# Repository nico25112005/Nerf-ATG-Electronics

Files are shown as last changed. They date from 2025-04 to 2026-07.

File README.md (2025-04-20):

# Nerf-ATG-Electronics

This repository contains the electronic design files for a custom printed circuit board (PCB) developed to enhance Nerf LaserOps blasters. The board utilizes an ESP32-S3 microcontroller to manage the blaster's functions and communicate via Bluetooth with a Unity application.

## Features

- Custom PCB design for Nerf LaserOps blasters
- ESP32-S3 microcontroller for improved performance and connectivity
- Bluetooth Classic for communication with a Unity application

## Installation

1. **PCB Assembly:**

   - Solder the components onto the board as per the schematic and Bill of Materials (BOM).

2. **Firmware Flashing:**

   - Flash the firmware onto the ESP32-S3. The firmware can be found in the Nerf-ATG-Firmware repository.

3. **Integration:**

   - Replace the original mainboard in the Nerf LaserOps blaster with the custom PCB.

4. **Unity App Setup:**

   - Install the Unity app from the Nerf-ATG-App repository on your device.
   - Pair the blaster with the app via Bluetooth.

## Usage

1. **Power On:**

   - Turn on the blaster.

2. **Connect to App:**

   - Open the Unity app and connect to the blaster via Bluetooth.

3. **Operation:**

   - Use the app to control and monitor the blaster’s functions.

## Contributing

Contributions are welcome! We are currently seeking assistance with programming the ESP32. If you have experience with ESP32 development, please consider contributing to the Nerf-ATG-Firmware repository. Please fork the repository and submit a pull request with your changes.

## Contact

For questions or support, please contact nico25112005.

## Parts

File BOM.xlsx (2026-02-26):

Reference | Qty | Value | DNP | Exclude from BOM | Exclude from Board | Footprint | Datasheet
BT2 | 1 | Battery (7.2V-10.8V) |  |  |  |  | ~
C2,C3,C4 | 3 | 100nF |  |  |  | PCM_JLCPCB:C_0603 | https://www.lcsc.com/datasheet/lcsc_datasheet_2211101700_YAGEO-CC0603KRX7R9BB104_C14663.pdf
C6 | 1 | 47pF |  |  |  | PCM_JLCPCB:C_0603 | https://www.lcsc.com/datasheet/lcsc_datasheet_2304140030_Samsung-Electro-Mechanics-CL10C470JB8NNNC_C1671.pdf
C7,C12,C14,C15,C16 | 5 | 22uF |  |  |  | PCM_JLCPCB:C_0805 | https://www.lcsc.com/datasheet/lcsc_datasheet_2304140030_Samsung-Electro-Mechanics-CL21A226MAQNNNE_C45783.pdf
C8,C9 | 2 | 1uF |  |  |  | PCM_JLCPCB:C_0603 | https://www.lcsc.com/datasheet/lcsc_datasheet_2304140030_Samsung-Electro-Mechanics-CL10A105KB8NNNC_C15849.pdf
C10,C11,C13 | 3 | 10uF |  |  |  | PCM_JLCPCB:C_0805 | https://www.lcsc.com/datasheet/lcsc_datasheet_2304140030_Samsung-Electro-Mechanics-CL21A106KAYNNNE_C15850.pdf
Camera_Interface1 | 1 | Conn_02x08_Counter_Clockwise |  |  |  |  | ~
J1 | 1 | Conn_01x02 |  |  |  | Connector_PinHeader_2.54mm:PinHeader_1x02_P2.54mm_Horizontal | ~
J2 | 1 | Conn_01x02_Socket |  |  |  | Connector_PinSocket_2.54mm:PinSocket_1x02_P2.54mm_Horizontal | ~
J3 | 1 | Dome |  |  |  | Connector_JST:JST_EH_B6B-EH-A_1x06_P2.50mm_Vertical | ~
J4 | 1 | USB_C_Receptacle_USB2.0_14P |  |  |  |  | https://www.usb.org/sites/default/files/documents/usb_type-c.zip
J5 | 1 | Motor1 |  |  |  | Connector_JST:JST_EH_B2B-EH-A_1x02_P2.50mm_Vertical | ~
J6 | 1 | Motor2 |  |  |  | Connector_JST:JST_EH_B2B-EH-A_1x02_P2.50mm_Vertical | ~
J7 | 1 | Speaker |  |  |  |  | ~
J8 | 1 | Conn_01x07 |  |  |  |  | ~
JP1 | 1 | Indoor/Outdoor |  | Excluded from BOM |  |  | ~
JP5,JP6,JP7,JP8 | 4 | Jumper |  | Excluded from BOM |  |  | ~
L1 | 1 | 6.8µH |  |  |  |  | ~
Q1 | 1 | S8550 120-200 |  |  |  | PCM_JLCPCB:Q_SOT-23 | https://www.lcsc.com/datasheet/lcsc_datasheet_2304140030_Jiangsu-Changjing-Electronics-Technology-Co---Ltd--S8550-RANGE-120-200_C105432.pdf
Q3 | 1 | S9015 300-400 |  |  |  | PCM_JLCPCB:Q_SOT-23 | https://www.lcsc.com/datasheet/lcsc_datasheet_1809211021_Jiangsu-Changjing-Electronics-Technology-Co---Ltd--S9015-RANGE-300-400_C2149.pdf
Q7,Q8,Q9 | 3 | S9014 |  |  |  | PCM_JLCPCB:Q_SOT-23 | https://wmsc.lcsc.com/wmsc/upload/file/pdf/v2/lcsc/2312291746_hongjiacheng-S9014_C20069130.pdf
R1,R11 | 2 | 5.1kΩ |  |  |  | PCM_JLCPCB:R_0603 | https://www.lcsc.com/datasheet/lcsc_datasheet_2206010116_UNI-ROYAL-Uniroyal-Elec-0603WAF5101T5E_C23186.pdf
R2,R7 | 2 | 300kΩ |  |  |  | PCM_JLCPCB:R_0603 | https://www.lcsc.com/datasheet/lcsc_datasheet_2206010116_UNI-ROYAL-Uniroyal-Elec-0603WAF3003T5E_C23024.pdf
R3 | 1 | 1Ω 1W |  |  |  |  | ~
R4 | 1 | 1Ω |  |  |  | PCM_JLCPCB:R_0603 | https://www.lcsc.com/datasheet/lcsc_datasheet_2206010130_UNI-ROYAL-Uniroyal-Elec-0603WAF100KT5E_C22936.pdf
R5 | 1 | 2.2kΩ |  |  |  | PCM_JLCPCB:R_0603 | https://www.lcsc.com/datasheet/lcsc_datasheet_2206010230_UNI-ROYAL-Uniroyal-Elec-0603WAF2201T5E_C4190.pdf
R6 | 1 | 10Ω |  |  |  | PCM_JLCPCB:R_0603 | https://www.lcsc.com/datasheet/lcsc_datasheet_2206010130_UNI-ROYAL-Uniroyal-Elec-0603WAF100JT5E_C22859.pdf
R8,R20 | 2 | 1kΩ |  |  |  | PCM_JLCPCB:R_0603 | https://www.lcsc.com/datasheet/lcsc_datasheet_2206010130_UNI-ROYAL-Uniroyal-Elec-0603WAF1001T5E_C21190.pdf
R9,R30 | 2 | 100Ω |  |  |  | PCM_JLCPCB:R_0603 | https://www.lcsc.com/datasheet/lcsc_datasheet_2411221126_UNI-ROYAL-Uniroyal-Elec-0603WAF1000T5E_C22775.pdf
R12,R18,R29 | 3 | 10kΩ |  |  |  | PCM_JLCPCB:R_0603 | https://www.lcsc.com/datasheet/lcsc_datasheet_2206010045_UNI-ROYAL-Uniroyal-Elec-0603WAF1002T5E_C25804.pdf
R13,R14 | 2 | TBD |  |  |  |  | ~
R15 | 1 | 634k |  |  |  |  | ~
R16,R21,R27 | 3 | 100kΩ |  |  |  | PCM_JLCPCB:R_0603 | https://www.lcsc.com/datasheet/lcsc_datasheet_2206010045_UNI-ROYAL-Uniroyal-Elec-0603WAF1003T5E_C25803.pdf
R17 | 1 | 22kΩ |  |  |  | PCM_JLCPCB:R_0603 | https://www.lcsc.com/datasheet/lcsc_datasheet_2206010030_UNI-ROYAL-Uniroyal-Elec-0603WAF2202T5E_C31850.pdf
R28,R33,R34 | 3 | 3.3kΩ |  |  |  | PCM_JLCPCB:R_0603 | https://www.lcsc.com/datasheet/lcsc_datasheet_2206010116_UNI-ROYAL-Uniroyal-Elec-0603WAF3301T5E_C22978.pdf
R31,R35,R36 | 3 | 4.7kΩ |  |  |  | PCM_JLCPCB:R_0603 | https://www.lcsc.com/datasheet/lcsc_datasheet_2206010116_UNI-ROYAL-Uniroyal-Elec-0603WAF4701T5E_C23162.pdf
SW2 | 1 | Trigger |  |  |  |  | ~
SW3 | 1 | Reload |  |  |  |  | ~
SW4,SW6 | 2 | SW_Push |  |  |  |  | ~
SW5 | 1 | SW_Push_DPDT |  |  |  |  | ~
U1 | 1 | AMS1117 |  |  |  | PCM_JLCPCB:SOT-223-3_L6.5-W3.4-P2.30-LS7.0-BR | https://www.lcsc.com/datasheet/lcsc_datasheet_2410121508_Advanced-Monolithic-Systems-AMS1117-3-3_C6186.pdf
U2 | 1 | ESP32-S3-WROOM-1 |  |  |  | RF_Module:ESP32-S3-WROOM-1 | https://www.espressif.com/sites/default/files/documentation/esp32-s3-wroom-1_wroom-1u_datasheet_en.pdf
U3 | 1 | TPS54302 |  |  |  | Package_TO_SOT_SMD:SOT-23-6 | http://www.ti.com/lit/ds/symlink/tps54302.pdf
U4 | 1 | MAX98357A |  |  |  | Package_DFN_QFN:TQFN-16-1EP_3x3mm_P0.5mm_EP1.23x1.23mm | https://www.analog.com/media/en/technical-documentation/data-sheets/MAX98357A-MAX98357B.pdf
U6 | 1 | LIS3DH |  |  |  | Package_LGA:LGA-16_3x3mm_P0.5mm_LayoutBorder3x5y | https://www.st.com/resource/en/datasheet/cd00274221.pdf
U7,U8 | 2 | LMV321IDBVR |  |  |  | PCM_JLCPCB:SOT-23-5_L3.0-W1.7-P0.95-LS2.8-BR | https://www.lcsc.com/datasheet/lcsc_datasheet_1809151123_Texas-Instruments-LMV321IDBVR_C7972.pdf
U9 | 1 | MCP4561-502E_MS |  |  |  | MCP4561_502E_MS:SOP65P490X110-8N

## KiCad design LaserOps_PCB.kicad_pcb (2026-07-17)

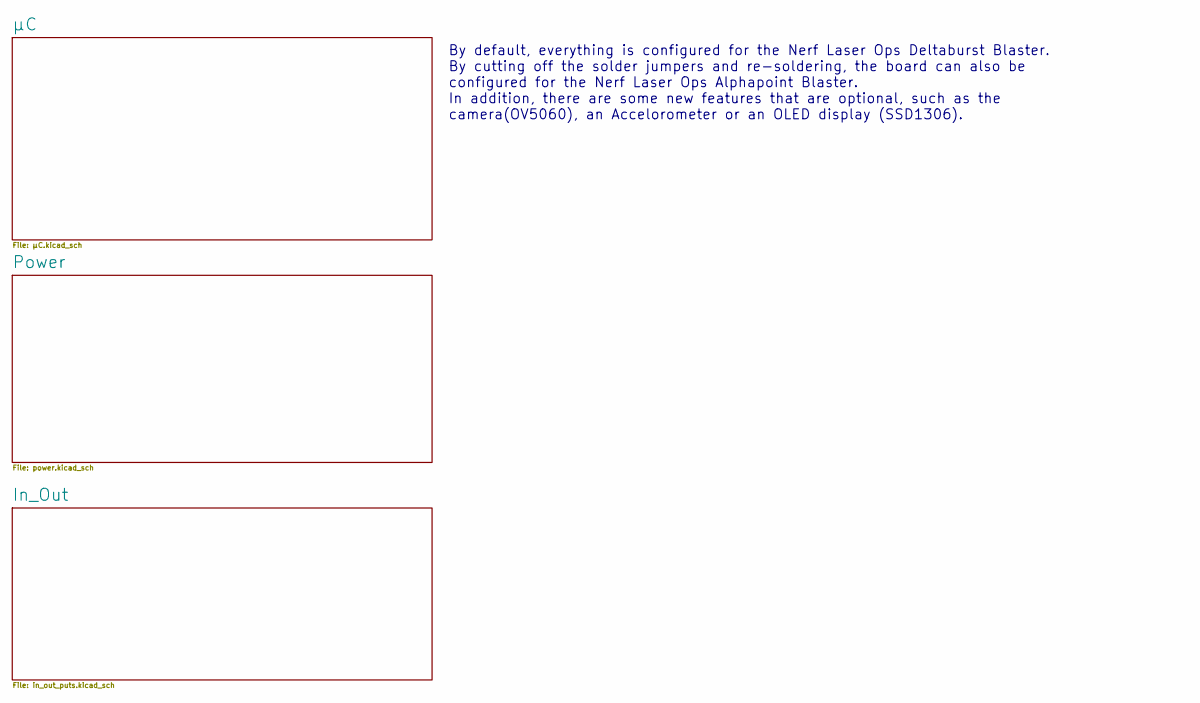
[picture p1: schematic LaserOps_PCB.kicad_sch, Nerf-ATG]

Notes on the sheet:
By default, everything is configured for the Nerf Laser Ops Deltaburst Blaster. By cutting off the solder jumpers and re-soldering, the board can also be configured for the Nerf Laser Ops Alphapoint Blaster. In addition, there are some new features that are optional, such as the camera(OV5060), an 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

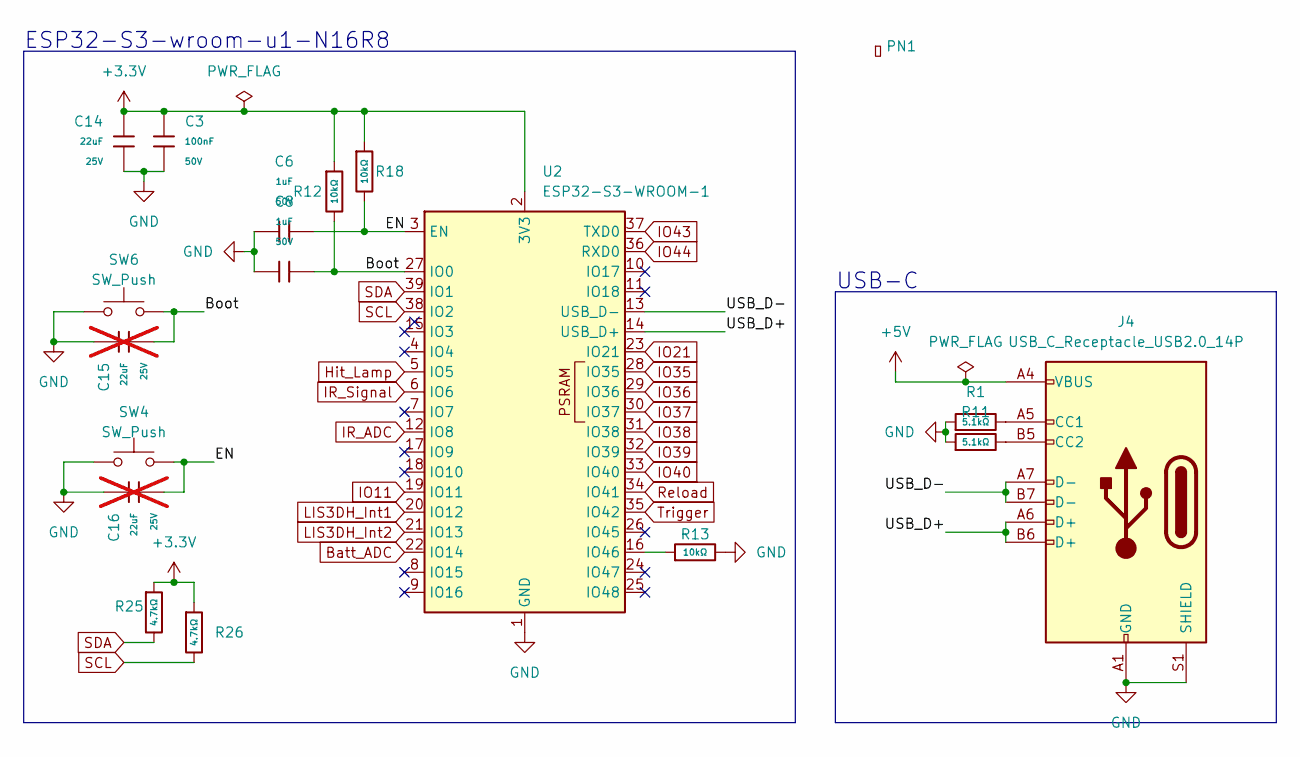
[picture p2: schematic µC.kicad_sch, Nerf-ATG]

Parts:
C3: 100nF; C_0805; Voltage Rated 50V; Tolerance ±10%; Part CC0805KRX7R9BB104; LCSC C49678
C6, C8: 1uF; C_0805; Voltage Rated 50V; Tolerance ±10%; Part CL21B105KBFNNNE; LCSC C28323
C14: 22uF; C_0805; Voltage Rated 25V; Tolerance ±20%; Part CL21A226MAQNNNE; LCSC C45783
C15, C16: 22uF; C_0805; Voltage Rated 25V; Tolerance ±20%; Part CL21A226MAQNNNE; LCSC C45783; not fitted
J4: USB_C_Receptacle_USB2.0_14P; USB_C_Receptacle_GCT_USB4085
PN1: Part_Num_JLCPCB
R1, R11: 5.1kΩ; R_0805; Overload Voltage (Max) 150V; Tolerance ±1%; Part 0805W8F5101T5E; LCSC C27834
R12, R13, R18: 10kΩ; R_0805; Overload Voltage (Max) 150V; Tolerance ±1%; Part 0805W8F1002T5E; LCSC C17414
R25, R26: 4.7kΩ; R_0805; Overload Voltage (Max) 150V; Tolerance ±1%; Part 0805W8F4701T5E; LCSC C17673
SW4, SW6: SW_Push; SW_SPST_CK_RS282G05A3
U2: ESP32-S3-WROOM-1

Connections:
+3.3V: C3.1, C14.1, R12.1, R18.1, R25.1, R26.1, U2.2 (3V3); also elsewhere on the board
+5V: J4.A4 (VBUS), J4.A9 (VBUS), J4.B4 (VBUS), J4.B9 (VBUS); also elsewhere on the board
/µC/Boot: C8.2, C15.2, R12.2, SW6.2, U2.27 (IO0)
/µC/EN: C6.2, C16.2, R18.2, SW4.2, U2.3 (EN)
/µC/USB_D+: J4.A6 (D+), J4.B6 (D+), U2.14 (USB_D+)
/µC/USB_D-: J4.A7 (D-), J4.B7 (D-), U2.13 (USB_D-)
Batt_ADC: U2.22 (IO14); also elsewhere on the board
GND: C3.2, C6.1, C8.1, C14.2, C15.1, C16.1, J4.A1 (GND), J4.A12 (GND), J4.B1 (GND), J4.B12 (GND), J4.S1 (SHIELD), R1.1, R11.1, R13.2, SW4.1, SW6.1, U2.1 (GND), U2.40 (GND), U2.41 (GND); also elsewhere on the board
Hit_Lamp: U2.5 (IO5); also elsewhere on the board
IO11: U2.19 (IO11); also elsewhere on the board
IO21: U2.23 (IO21); also elsewhere on the board
IO35: U2.28 (IO35); also elsewhere on the board
IO36: U2.29 (IO36); also elsewhere on the board
IO37: U2.30 (IO37); also elsewhere on the board
IO38: U2.31 (IO38); also elsewhere on the board
IO39: U2.32 (IO39); also elsewhere on the board
IO40: U2.33 (IO40); also elsewhere on the board
IO43: U2.37 (TXD0); also elsewhere on the board
IO44: U2.36 (RXD0); also elsewhere on the board
IR_ADC: U2.12 (IO8); also elsewhere on the board
IR_Signal: U2.6 (IO6); also elsewhere on the board
LIS3DH_Int1: U2.20 (IO12); also elsewhere on the board
LIS3DH_Int2: U2.21 (IO13); also elsewhere on the board
unnamed: J4.A5 (CC1), R1.2
unnamed: J4.B5 (CC2), R11.2
unnamed: R13.1, U2.16 (IO46)
Reload: U2.34 (IO41); also elsewhere on the board
SCL: R26.2, U2.38 (IO2); also elsewhere on the board
SDA: R25.2, U2.39 (IO1); also elsewhere on the board
Trigger: U2.35 (IO42); also elsewhere on the board

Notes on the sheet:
ESP32-S3-wroom-u1-N16R8
USB-C

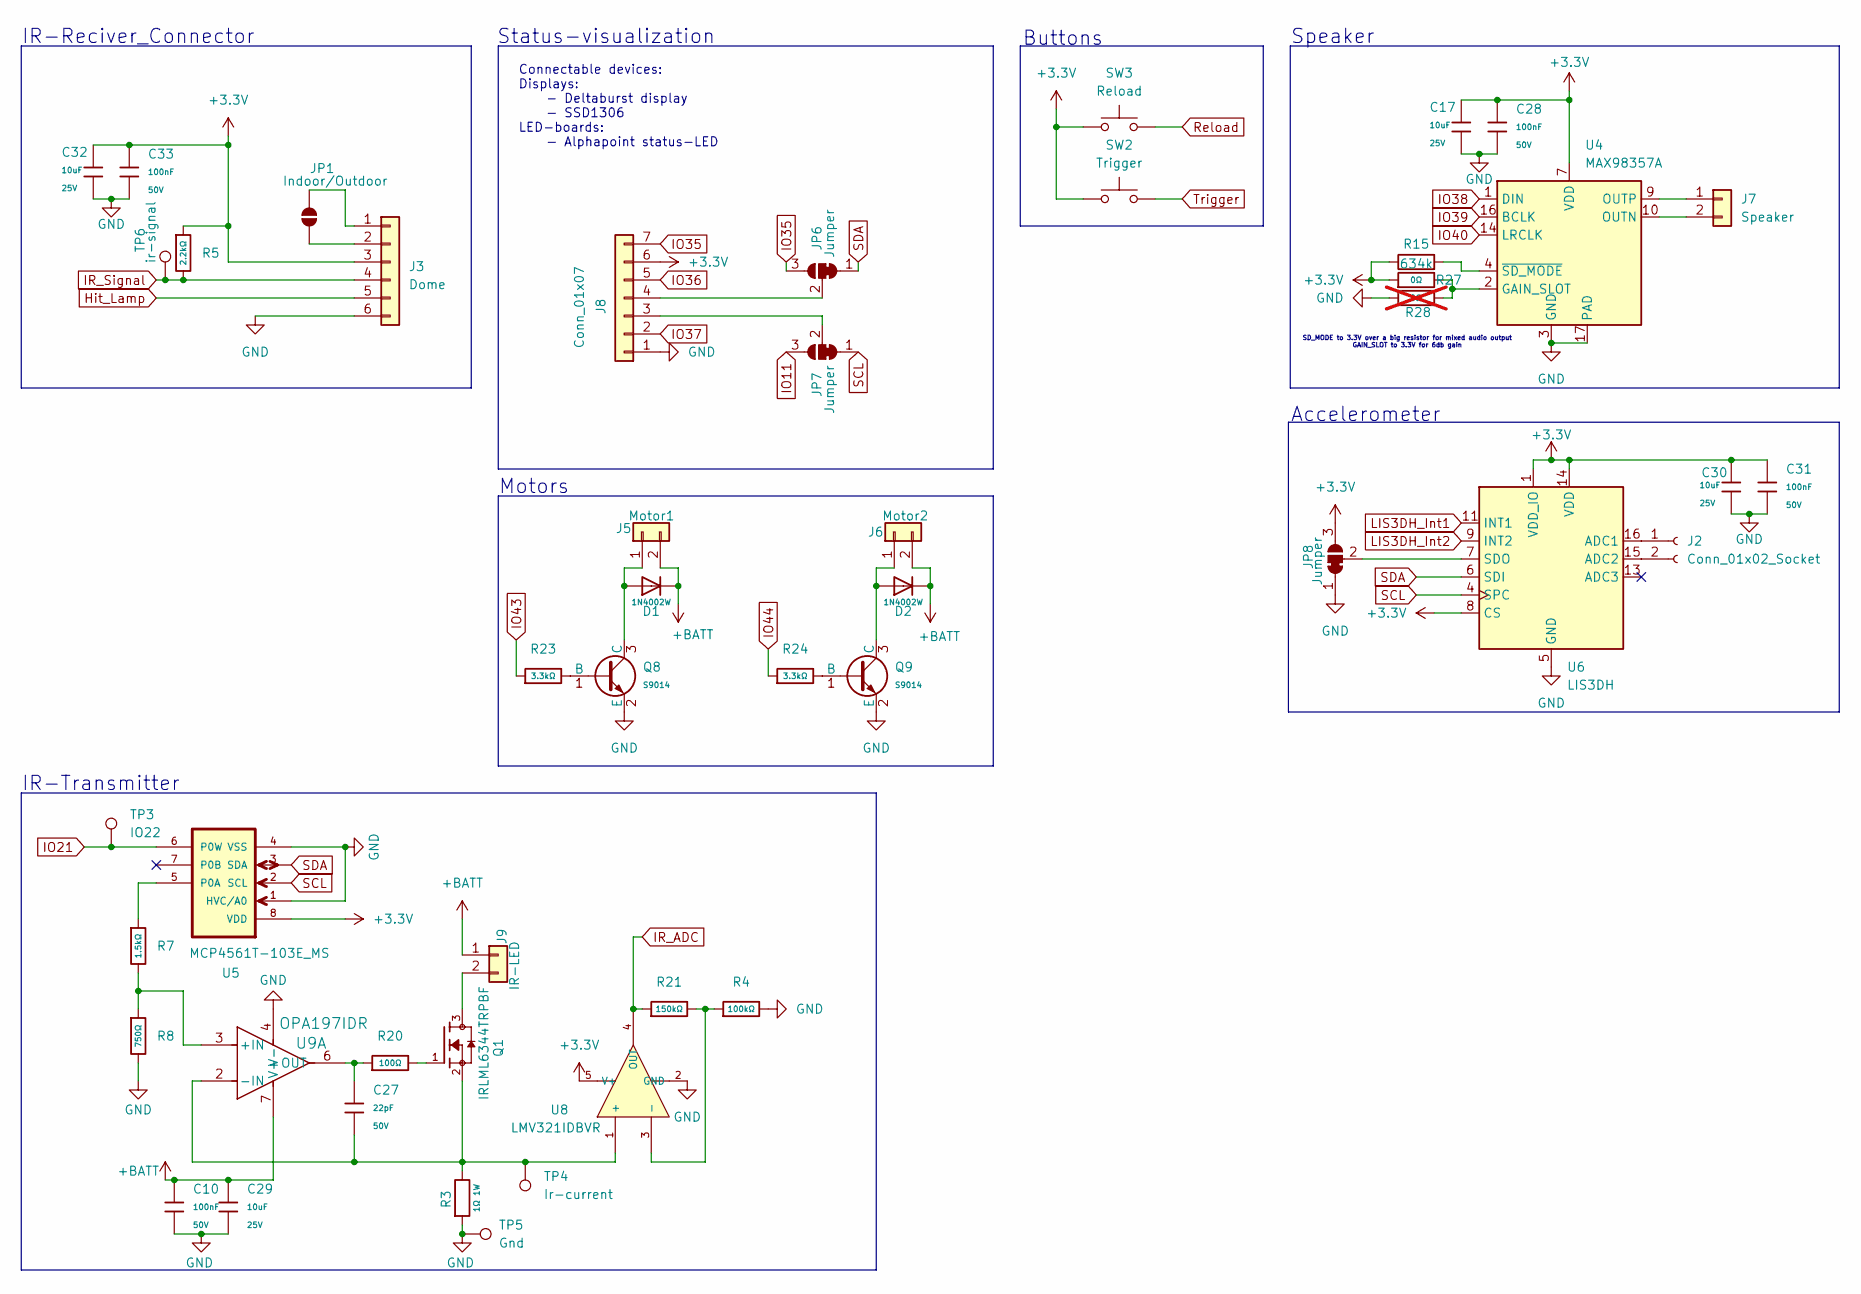
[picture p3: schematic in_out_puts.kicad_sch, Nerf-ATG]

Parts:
C10, C28, C31, C33: 100nF; C_0805; Voltage Rated 50V; Tolerance ±10%; Part CC0805KRX7R9BB104; LCSC C49678
C17, C29, C30, C32: 10uF; C_0805; Voltage Rated 25V; Tolerance ±10%; Part CL21A106KAYNNNE; LCSC C15850
C27: 22pF; C_0805; Voltage Rated 50V; Tolerance ±5%; Part CL21C220JBANNNC; LCSC C1804
D1, D2: 1N4002W; D_SOD-123FL; Forward Voltage (Vf@If) 1V@1.0A; Reverse Voltage (Vr) 100V; Part 1N4002W; LCSC C18199086
J2: Conn_01x02_Socket; PinHeader_1x02_P2.54mm_Vertical
J3: Dome; JST_PH_B6B-PH-SM4-TB_1x06-1MP_P2.00mm_Vertical
J5: Motor1; JST_PH_B2B-PH-SM4-TB_1x02-1MP_P2.00mm_Vertical
J6: Motor2; JST_PH_B2B-PH-SM4-TB_1x02-1MP_P2.00mm_Vertical
J7: Speaker; JST_PH_B2B-PH-SM4-TB_1x02-1MP_P2.00mm_Vertical
J8: Conn_01x07; JST_PH_S7B-PH-SM4-TB_1x07-1MP_P2.00mm_Horizontal
J9: IR-LED; PinHeader_1x02_P2.54mm_Vertical
JP1: Indoor/Outdoor; SolderJumper-2_P1.3mm_Open_RoundedPad1.0x1.5mm
JP6, JP7, JP8: Jumper; SolderJumper-3_P1.3mm_Bridged12_RoundedPad1.0x1.5mm_NumberL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
Q1: IRLML6344TRPBF; TRANS_IRLML6344TRPBF; PARTREV December 19, 2014
Q8, Q9: S9014; Q_SOT-23; Part S9014; LCSC C20069130
R3: 1Ω 1W; R_2512_6332Metric_Pad1.40x3.35mm_HandSolder
R4: 100kΩ; R_0805; Overload Voltage (Max) 150V; Tolerance ±1%; Part 0805W8F1003T5E; LCSC C149504
R5: 2.2kΩ; R_0805; Overload Voltage (Max) 150V; Tolerance ±1%; Part 0805W8F2201T5E; LCSC C17520
R7: 1.5kΩ; R_0805; Overload Voltage (Max) 150V; Tolerance ±1%; Part 0805W8F1501T5E; LCSC C4310
R8: 750Ω; R_0805; Overload Voltage (Max) 150V; Tolerance ±1%; Part 0805W8F7500T5E; LCSC C17818
R15: 634k; R_0805_2012Metric_Pad1.20x1.40mm_HandSolder
R20: 100Ω; R_0805; Overload Voltage (Max) 150V; Tolerance ±1%; Part 0805W8F1000T5E; LCSC C17408
R21: 150kΩ; R_0805; Overload Voltage (Max) 150V; Tolerance ±1%; Part 0805W8F1503T5E; LCSC C17470
R23, R24: 3.3kΩ; R_0805; Overload Voltage (Max) 150V; Tolerance ±1%; Part 0805W8F3301T5E; LCSC C26010
R27: 0Ω; R_0805; Overload Voltage (Max) 150V; Tolerance ±1%; Part 0805W8F0000T5E; LCSC C17477
R28: 0Ω; R_0805; Overload Voltage (Max) 150V; Tolerance ±1%; Part 0805W8F0000T5E; LCSC C17477; not fitted
SW2: Trigger; PinHeader_1x02_P2.54mm_Vertical
SW3: Reload; PinHeader_1x02_P2.54mm_Vertical
TP3: IO22; TestPoint_Pad_D1.5mm
TP4: Ir-current; TestPoint_Pad_D1.5mm
TP5: Gnd; TestPoint_Pad_D2.0mm
TP6: ir-signal; TestPoint_Pad_D1.5mm
U4: MAX98357A; TQFN-16-1EP_3x3mm_P0.5mm_EP1.23x1.23mm
U5: MCP4561T-103E_MS; SOP65P490X110-8N; MPN MCP4531T-103E/MS
U6: LIS3DH; LGA-16_3x3mm_P0.5mm_LayoutBorder3x5y
U8: LMV321IDBVR; SOT-23-5_L3.0-W1.7-P0.95-LS2.8-BR; Part LMV321IDBVR; LCSC C7972
U9: OPA197IDR; D0008A-IPC_A

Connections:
+3.3V: C17.1, C28.1, C30.1, C31.1, C32.1, C33.1, J3.3, J8.6, JP8.3 (B), R5.1, R15.1, R27.1, SW2.1, SW3.1, U4.7 (VDD), U4.8 (VDD), U5.8 (VDD), U6.1 (VDD_IO), U6.8 (CS), U6.14 (VDD), U8.5 (V+); also elsewhere on the board
+BATT: C10.1, C29.1, D1.1, D2.1, J5.2, J6.2, J9.1, U9.7 (V+); also elsewhere on the board
GND: C10.2, C17.2, C28.2, C29.2, C30.2, C31.2, C32.2, C33.2, J3.6, J8.1, JP8.1 (A), Q8.2 (E), Q9.2 (E), R3.2, R4.2, R8.2, R28.1, TP5.1, U4.3 (GND), U4.11 (GND), U4.15 (GND), U4.17 (PAD), U5.1 (HVC/A0), U5.4 (VSS), U6.5 (GND), U6.10 (GND), U6.12 (GND), U8.2 (GND), U9.4 (V-); also elsewhere on the board
Hit_Lamp: J3.5; also elsewhere on the board
IO11: JP7.3 (B); also elsewhere on the board
IO21: TP3.1, U5.6 (P0W); also elsewhere on the board
IO35: J8.7, JP6.3 (B); also elsewhere on the board
IO36: J8.5; also elsewhere on the board
IO37: J8.2; also elsewhere on the board
IO38: U4.1 (DIN); also elsewhere on the board
IO39: U4.16 (BCLK); also elsewhere on the board
IO40: U4.14 (LRCLK); also elsewhere on the board
IO43: R23.1; also elsewhere on the board
IO44: R24.1; also elsewhere on the board
IR_ADC: R21.1, U8.4 (OUT); also elsewhere on the board
IR_Signal: J3.4, R5.2, TP6.1; also elsewhere on the board
LIS3DH_Int1: U6.11 (INT1); also elsewhere on the board
LIS3DH_Int2: U6.9 (INT2); also elsewhere on the board
unnamed: J2.1, U6.16 (ADC1)
unnamed: J2.2, U6.15 (ADC2)
unnamed: J3.1, JP1.2 (B)
unnamed: J3.2, JP1.1 (A)
unnamed: D1.2, J5.1, Q8.3 (C)
unnamed: D2.2, J6.1, Q9.3 (C)
unnamed: J7.1, U4.9 (OUTP)
unnamed: J7.2, U4.10 (OUTN)
unnamed: J8.3, JP7.2 (C)
unnamed: J8.4, JP6.2 (C)
unnamed: J9.2, Q1.3
unnamed: JP8.2 (C), U6.7 (SDO)
unnamed: Q1.1, R20.2
unnamed: Q8.1 (B), R23.2
unnamed: Q9.1 (B), R24.2
unnamed: R27.2, R28.2, U4.2 (GAIN_SLOT)
unnamed: R15.2, U4.4 (~SD_MODE)
unnamed: R7.1, U5.5 (P0A)
unnamed: C27.2, Q1.2, R3.1, TP4.1, U8.1 (+), U9.2 (-IN)
unnamed: R4.1, R21.2, U8.3 (-)
unnamed: R7.2, R8.1, U9.3 (+IN)
unnamed: C27.1, R20.1, U9.6 (OUT)
Reload: SW3.2; also elsewhere on the board
SCL: JP7.1 (A), U5.2 (SCL), U6.4 (SPC); also elsewhere on the board
SDA: JP6.1 (A), U5.3 (SDA), U6.6 (SDI); also elsewhere on the board
Trigger: SW2.2; also elsewhere on the board

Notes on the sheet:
Status-visualization
IR-Transmitter
Connectable devices: Displays: - Deltaburst display - SSD1306 LED-boards: - Alphapoint status-LED
Speaker
SD_MODE to 3.3V over a big resistor for mixed audio output GAIN_SLOT to 3.3V for 6db gain
Buttons
Accelerometer
IR-Reciver_Connector
Motors

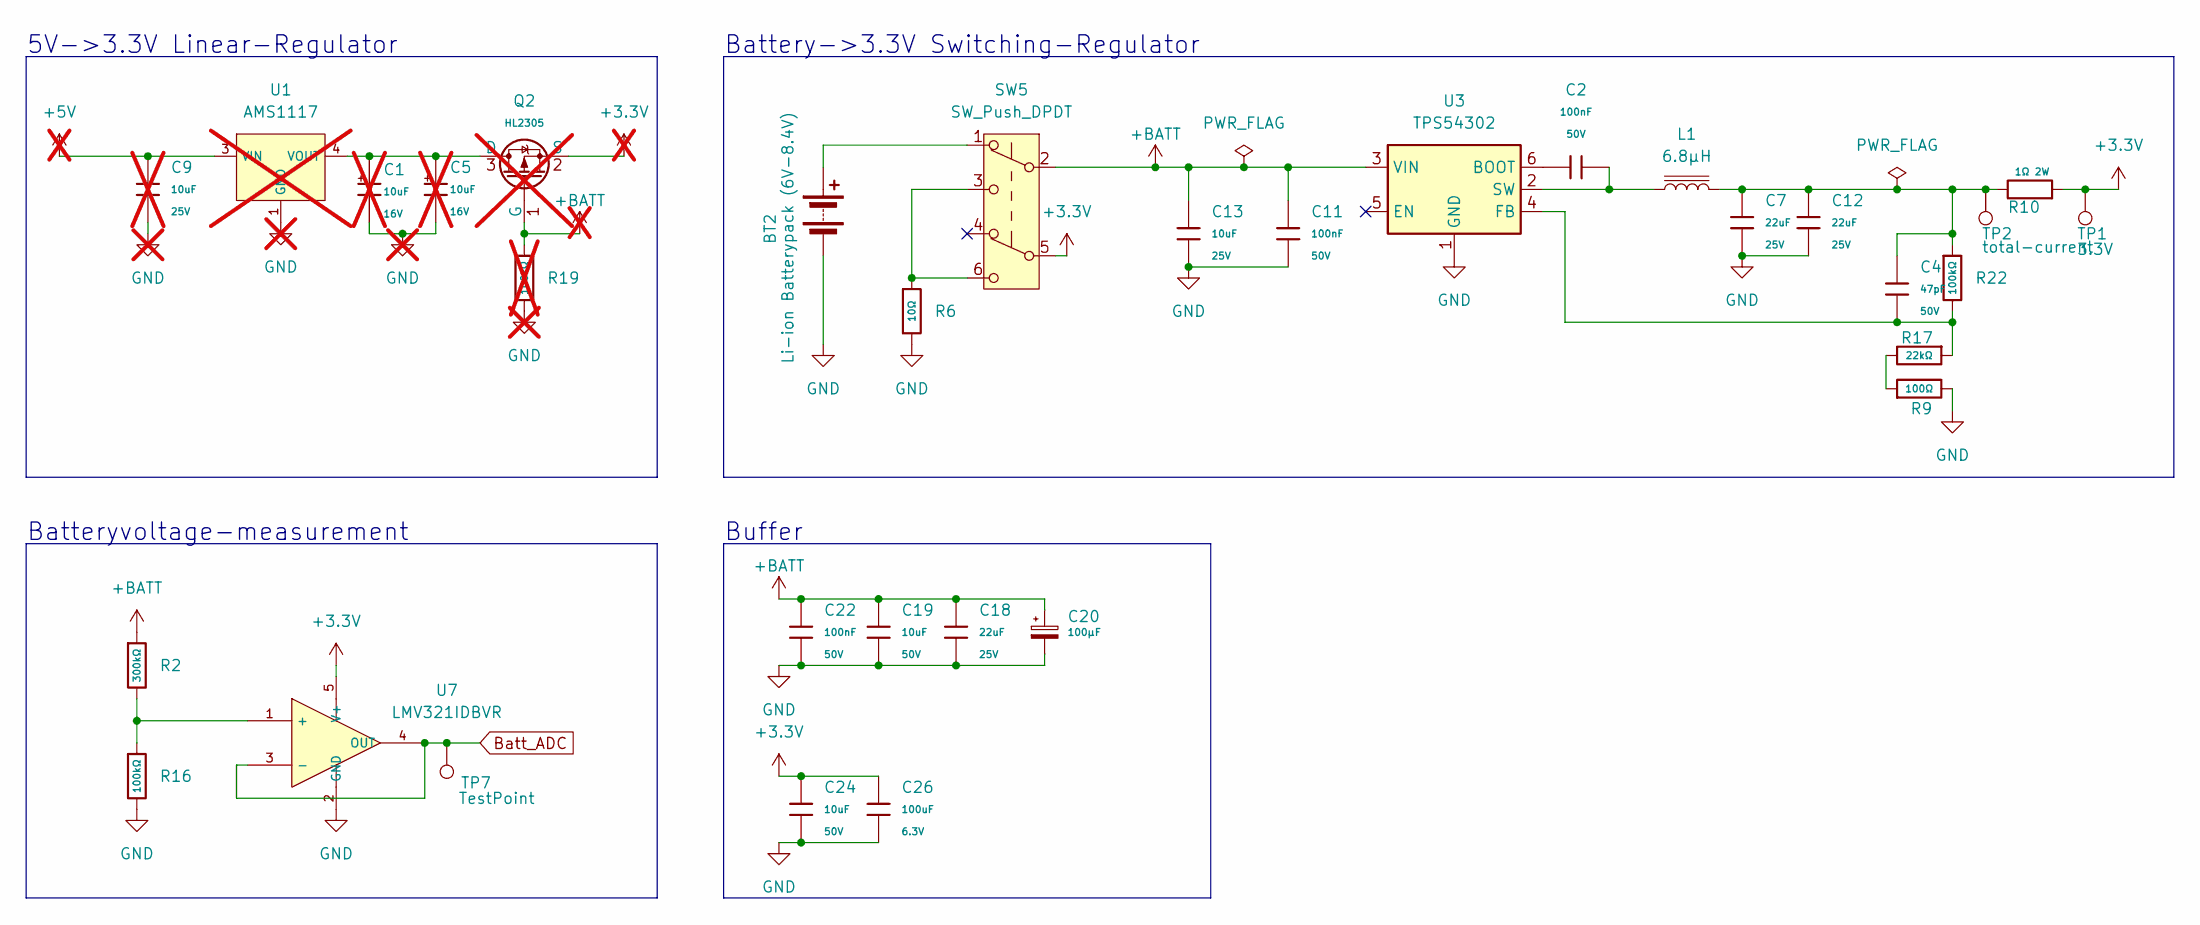
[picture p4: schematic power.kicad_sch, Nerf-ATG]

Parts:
BT2: Li-ion Batterypack (6V-8.4V); PinHeader_1x02_P2.54mm_Vertical
C1, C5: 10uF; C_CASE-A-3216-18(mm); Tolerance ±10%; Rated Voltage 16V; Part TAJA106K016RNJ; LCSC C7171; not fitted
C2, C11: 100nF; C_0805; Voltage Rated 50V; Tolerance ±10%; Part CC0805KRX7R9BB104; LCSC C49678
C4: 47pF; C_0805; Voltage Rated 50V; Tolerance ±5%; Part CL21C470JBANNNC; LCSC C14857
C7, C12: 22uF; C_0805; Voltage Rated 25V; Tolerance ±20%; Part CL21A226MAQNNNE; LCSC C45783
C9: 10uF; C_0805; Voltage Rated 25V; Tolerance ±10%; Part CL21A106KAYNNNE; LCSC C15850; not fitted
C13: 10uF; C_0805; Voltage Rated 25V; Tolerance ±10%; Part CL21A106KAYNNNE; LCSC C15850
C18: 22uF; C_1206; Voltage Rated 25V; Tolerance ±10%; Part CL31A226KAHNNNE; LCSC C12891
C19, C24: 10uF; C_1206; Voltage Rated 50V; Tolerance ±10%; Part CL31A106KBHNNNE; LCSC C13585
C20: 100µF; CP_Radial_D5.0mm_P2.50mm
C22: 100nF; C_1206; Voltage Rated 50V; Tolerance ±10%; Part CL31B104KBCNNNC; LCSC C24497
C26: 100uF; C_1206; Voltage Rated 6.3V; Tolerance ±20%; Part CL31A107MQHNNNE; LCSC C15008
L1: 6.8µH; L_Coilcraft_LPS4018
Q2: HL2305; Q_SOT-23; Part HL2305; LCSC C28646261; not fitted
R2: 300kΩ; R_0805; Overload Voltage (Max) 150V; Tolerance ±1%; Part 0805W8F3003T5E; LCSC C17616
R6: 10Ω; R_0805; Overload Voltage (Max) 150V; Tolerance ±1%; Part 0805W8F100JT5E; LCSC C17415
R9: 100Ω; R_0805; Overload Voltage (Max) 150V; Tolerance ±1%; Part 0805W8F1000T5E; LCSC C17408
R10: 1Ω 2W; R_2512_6332Metric_Pad1.40x3.35mm_HandSolder
R16, R22: 100kΩ; R_0805; Overload Voltage (Max) 150V; Tolerance ±1%; Part 0805W8F1003T5E; LCSC C149504
R17: 22kΩ; R_0805; Overload Voltage (Max) 150V; Tolerance ±1%; Part 0805W8F2202T5E; LCSC C17560
R19: 100kΩ; R_0805; Overload Voltage (Max) 150V; Tolerance ±1%; Part 0805W8F1003T5E; LCSC C149504; not fitted
SW5: SW_Push_DPDT; MHPS2266
TP1: 3.3V; TestPoint_Pad_D2.0mm
TP2: total-current; TestPoint_Pad_D1.5mm
TP7: TestPoint; TestPoint_Pad_D1.5mm
U1: AMS1117; SOT-223-3_L6.5-W3.4-P2.30-LS7.0-BR; Output Voltage 3.3V; Dropout Voltage 1.3V@(800mA); Part AMS1117-3.3; LCSC C6186; not fitted
U3: TPS54302; SOT-23-6
U7: LMV321IDBVR; SOT-23-5_L3.0-W1.7-P0.95-LS2.8-BR; Part LMV321IDBVR; LCSC C7972

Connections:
+3.3V: C24.1, C26.1, Q2.2 (S), R10.2, SW5.5 (B), TP1.1, U7.5 (V+); also elsewhere on the board
+5V: C9.1, U1.3 (VIN); also elsewhere on the board
+BATT: C11.1, C13.1, C18.1, C19.1, C20.1, C22.1, Q2.1 (G), R2.1, R19.1, SW5.2 (B), U3.3 (VIN); also elsewhere on the board
Batt_ADC: TP7.1, U7.3 (-), U7.4 (OUT); also elsewhere on the board
GND: BT2.2 (-), C1.2, C5.2, C7.2, C9.2, C11.2, C12.2, C13.2, C18.2, C19.2, C20.2, C22.2, C24.2, C26.2, R6.2, R9.2, R16.2, R19.2, U1.1 (GND), U3.1 (GND), U7.2 (GND); also elsewhere on the board
unnamed: BT2.1 (+), SW5.1 (A)
unnamed: C4.2, C7.1, C12.1, L1.2, R10.1, R22.1, TP2.1
unnamed: C1.1, C5.1, Q2.3 (D), U1.2 (VOUT), U1.4 (VOUT)
unnamed: R6.1, SW5.3 (C), SW5.6 (C)
unnamed: R9.1, R17.2
unnamed: C2.1, U3.6 (BOOT)
unnamed: C4.1, R17.1, R22.2, U3.4 (FB)
unnamed: C2.2, L1.1, U3.2 (SW)
unnamed: R2.2, R16.1, U7.1 (+)

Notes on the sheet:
Battery->3.3V Switching-Regulator
Buffer
5V->3.3V Linear-Regulator
Batteryvoltage-measurement

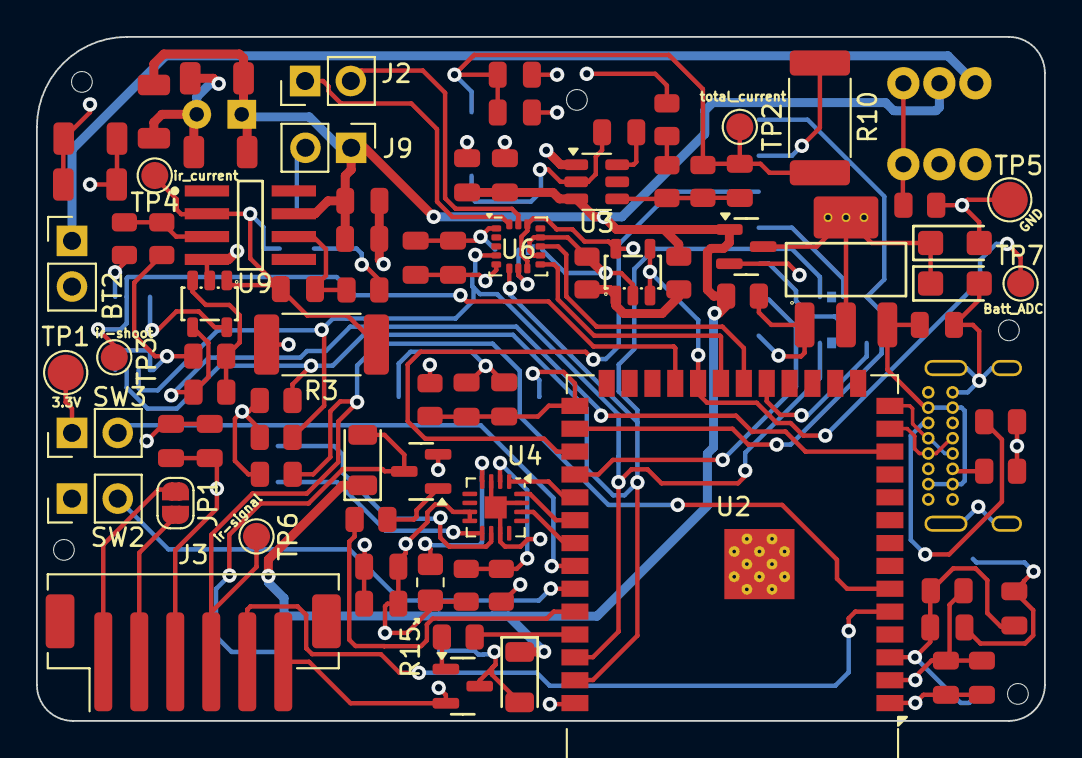
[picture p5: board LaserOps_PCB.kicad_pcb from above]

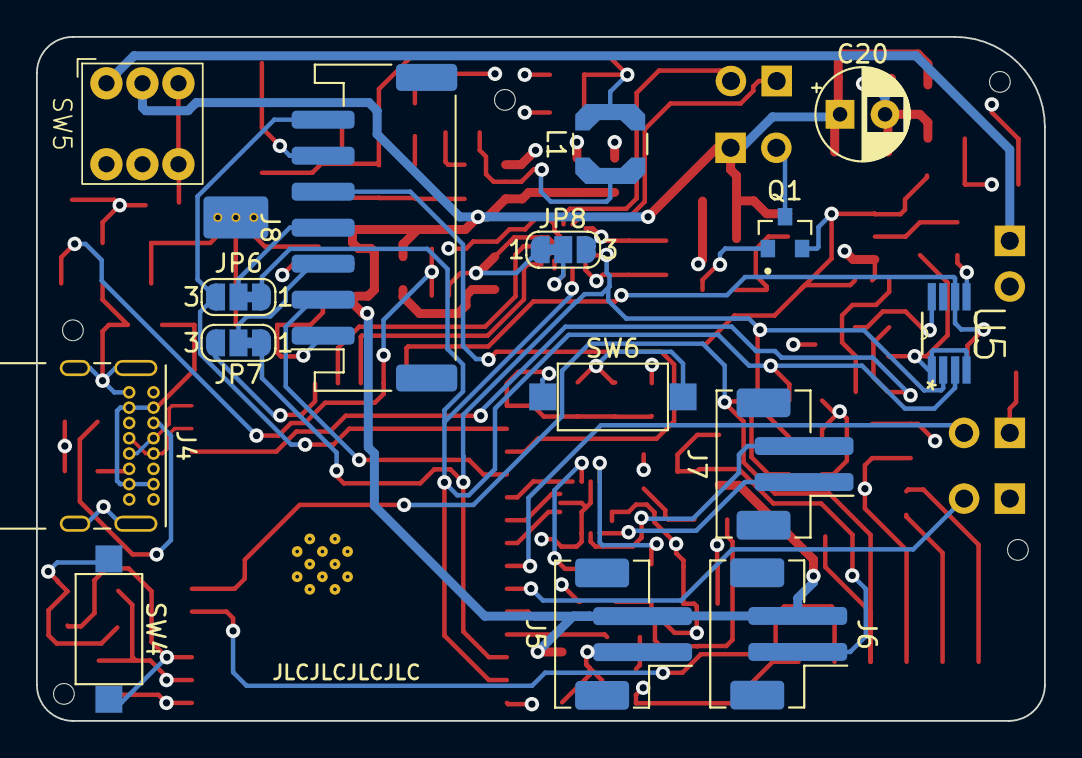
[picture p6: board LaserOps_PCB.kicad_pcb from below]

Board: 4 copper layers, 56.0 x 38.0 mm, 98 parts (16 on the bottom side), 61 nets.

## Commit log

2025-04-14 late night schmeatic with gotzi
    [LaserOps_PCB.kicad_sch, in_out_puts.kicad_sch, power.kicad_sch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]
2025-04-20 simulated IR-constant-current circuit, worked on schematic
    [LaserOps_PCB.kicad_pcb, LaserOps_PCB.kicad_sch, in_out_puts.kicad_sch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]
2025-05-09 prepared for jlcpcb ordering.
    [LaserOps_PCB.kicad_sch, in_out_puts.kicad_sch, power.kicad_sch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]
2026-02-26 checked and fixed schematic, analized it with traceformer.io ai
    [BOM.xlsx, LaserOps_PCB.kicad_pcb, LaserOps_PCB.kicad_sch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]
2026-02-26 replaced ir-led constant current circuit
    [in_out_puts.kicad_sch, power.kicad_sch, µC.kicad_sch]
2026-02-26 pcb layout designing
    [LaserOps_PCB-CuBottom.gbr, LaserOps_PCB-CuIn1.gbr, LaserOps_PCB-CuIn2.gbr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]
2026-02-27 finished pcb design and routing
2026-02-27 finished pcb design and ordered first patch pcba (2pcs)
2026-03-19 pcb didn't commit correctly
    [LaserOps_PCB-CuBottom.gbr, LaserOps_PCB-CuIn1.gbr, LaserOps_PCB-CuIn2.gbr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]
